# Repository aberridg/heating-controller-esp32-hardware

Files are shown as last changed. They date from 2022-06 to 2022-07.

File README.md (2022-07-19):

# heating-controller-esp32-hardware

This is a multi-zone heating controller, based on an ESP-32.

It uses Triacs for switching the boiler, pump and thermostats.

Right now, it is set up for 3 zones plus Domestic Hot Water.

It's designed to be used with this firmware:

https://github.com/aberridg/heating-controller-esp32-mqtt

The design can be used with physical thermostats or with triggering
via MQTT (for use with home automation systems such as Home Assistant).

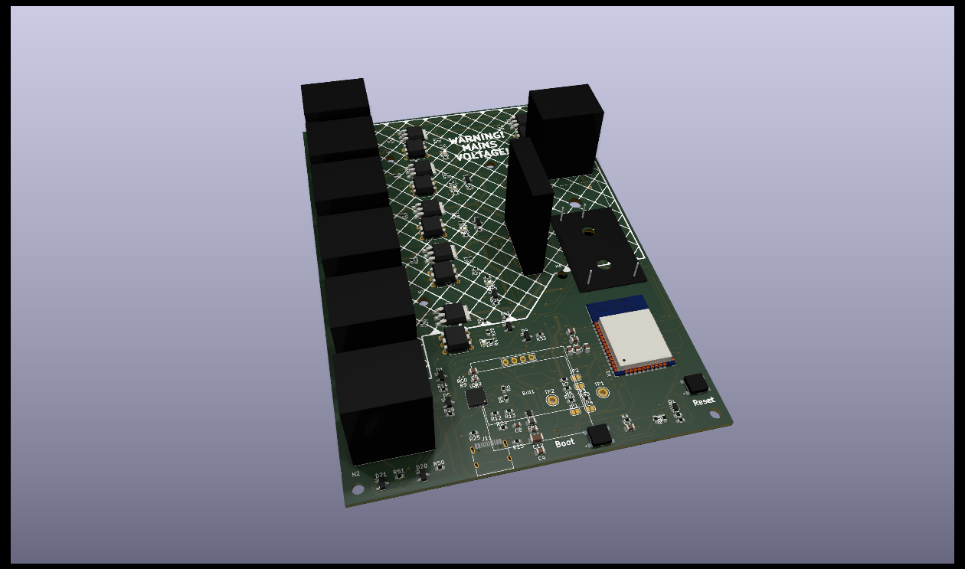
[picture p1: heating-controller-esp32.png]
3D Rendering of PCB


[Schematic](/heating-controller-esp32.pdf)

I'm having some PCBs made/assembled by JLCPCB, so if you want one, let me know (via LinkedIn - link in my bio)! Or if you can't do that, raise an issue.

IMPORTANT: v1.0 - the connector for the thermostats is the wrong way round on the PCB, so the pin numbers are not consistent with the others. No matter, just wire accordingly. For reference, GND is the upper pin, closest to the bottom edge of the board.

Also IMPORTANT: v1.0 - to flash the ESP32, hold down the Boot button and press reset.

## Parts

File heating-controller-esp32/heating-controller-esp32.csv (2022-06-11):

Comment | Designator | Footprint | LCSC
SSD1306 | Brd1 | Andrew_Custom:128x64OLED
1uF | C1,C6 | Capacitor_SMD:C_0805_2012Metric | C28323
4.7uF | C10 | Capacitor_SMD:C_0603_1608Metric | C19666
10uF | C12 | Capacitor_SMD:C_1206_3216Metric | C7171
100nF | C2,C3,C5,C7,C9 | Capacitor_SMD:C_0805_2012Metric | C49678
1.0uF | C4 | Capacitor_SMD:C_0805_2012Metric | C28323
10nF/100V | C8,C11 | Capacitor_SMD:C_0603_1608Metric | C84709
RED | D14,D15,D16,D17,D18,D19 | LED_SMD:LED_0603_1608Metric | C2286
ACS2 | D2,D3,D4,D6,D11,D12 | Package_TO_SOT_SMD:TO-252-3_TabPin4
~ | D1,D5,D7,D8,D9,D10,D13,D20,D21 | Package_TO_SOT_SMD:SOT-23 | C255581
LVR200S-240 | F1 | SamacSys_Parts:LVR200S240
MF-RM005_240-2 | F2 | SamacSys_Parts:MFRM0052402
Ferrite_Bead | FB1 | Inductor_SMD:L_0805_2012Metric | C1015
MountingHole | H1,H2,H3,H4,H5,H6,H7,H8 | MountingHole:MountingHole_3.2mm_M3_DIN965
431151015826 | J1,J2 | SamacSys_Parts:431151015826 | C318884
USB_C_Receptacle_USB2.0 | J11 | Connector_USB:USB_C_Receptacle_HRO_TYPE-C-31-M-12 | C165948
76829-0104 | J3,J4,J5,J6,J7,J8,J9 | SamacSys_Parts:736303
i2cPU | JP1,JP4 | Jumper:SolderJumper-2_P1.3mm_Bridged_RoundedPad1.0x1.5mm
SolderJumper_2_Bridged | JP2 | Jumper:SolderJumper-2_P1.3mm_Open_RoundedPad1.0x1.5mm
SolderJumper_2_Bridged | JP3 | Jumper:SolderJumper-2_P1.3mm_Bridged_RoundedPad1.0x1.5mm
IRM-01-3.3 | PS1 | SamacSys_Parts:IRM015
MBT3904DW1 | Q1 | Package_TO_SOT_SMD:SOT-363_SC-70-6 | C896759
12K | R1 | Resistor_SMD:R_0603_1608Metric | C22790
47K | R10 | Resistor_SMD:R_0402_1005Metric | C25792
470R | R12,R13 | Resistor_SMD:R_0603_1608Metric | C23179
270R | R15,R18,R21,R28,R35,R38 | Resistor_SMD:R_0603_1608Metric | C22966
360R | R16,R17,R19,R20,R22,R27,R29,R30,R36,R37,R39,R40 | Resistor_SMD:R_0603_1608Metric | C25194
1M | R23 | Resistor_SMD:R_0603_1608Metric | C22935
5.1K | R24 | Resistor_SMD:R_0603_1608Metric | C23186
~ | R14,R25,R26,R31,R32,R33,R34,R41,R50,R51 | Resistor_SMD:R_0603_1608Metric | C23162
22R | R4 | Resistor_SMD:R_0603_1608Metric | C23345
10K | R2,R3,R7,R8,R11,R42,R43 | Resistor_SMD:R_0603_1608Metric | C25804
1K | R44,R45,R46,R47,R48,R49 | Resistor_SMD:R_0603_1608Metric | C21190
27R | R5,R6 | Resistor_SMD:R_0603_1608Metric | C22966
24K | R9 | Resistor_SMD:R_0402_1005Metric | C25769
TestPoint | TP1,TP2 | TestPoint:TestPoint_Keystone_5005-5009_Compact
ESP32-WROOM-32U | U1 | RF_Module:ESP32-WROOM-32 | C82899
CP2102N-A01-GQFN28 | U2 | Package_DFN_QFN:QFN-28-1EP_5x5mm_P0.5mm_EP3.35x3.35mm | C6568
MOC3061M | U4,U6,U7,U8,U9,U10 | Package_DIP:DIP-6_W7.62mm | C8918
~ | U5 | Package_TO_SOT_SMD:SOT-666 | C15999

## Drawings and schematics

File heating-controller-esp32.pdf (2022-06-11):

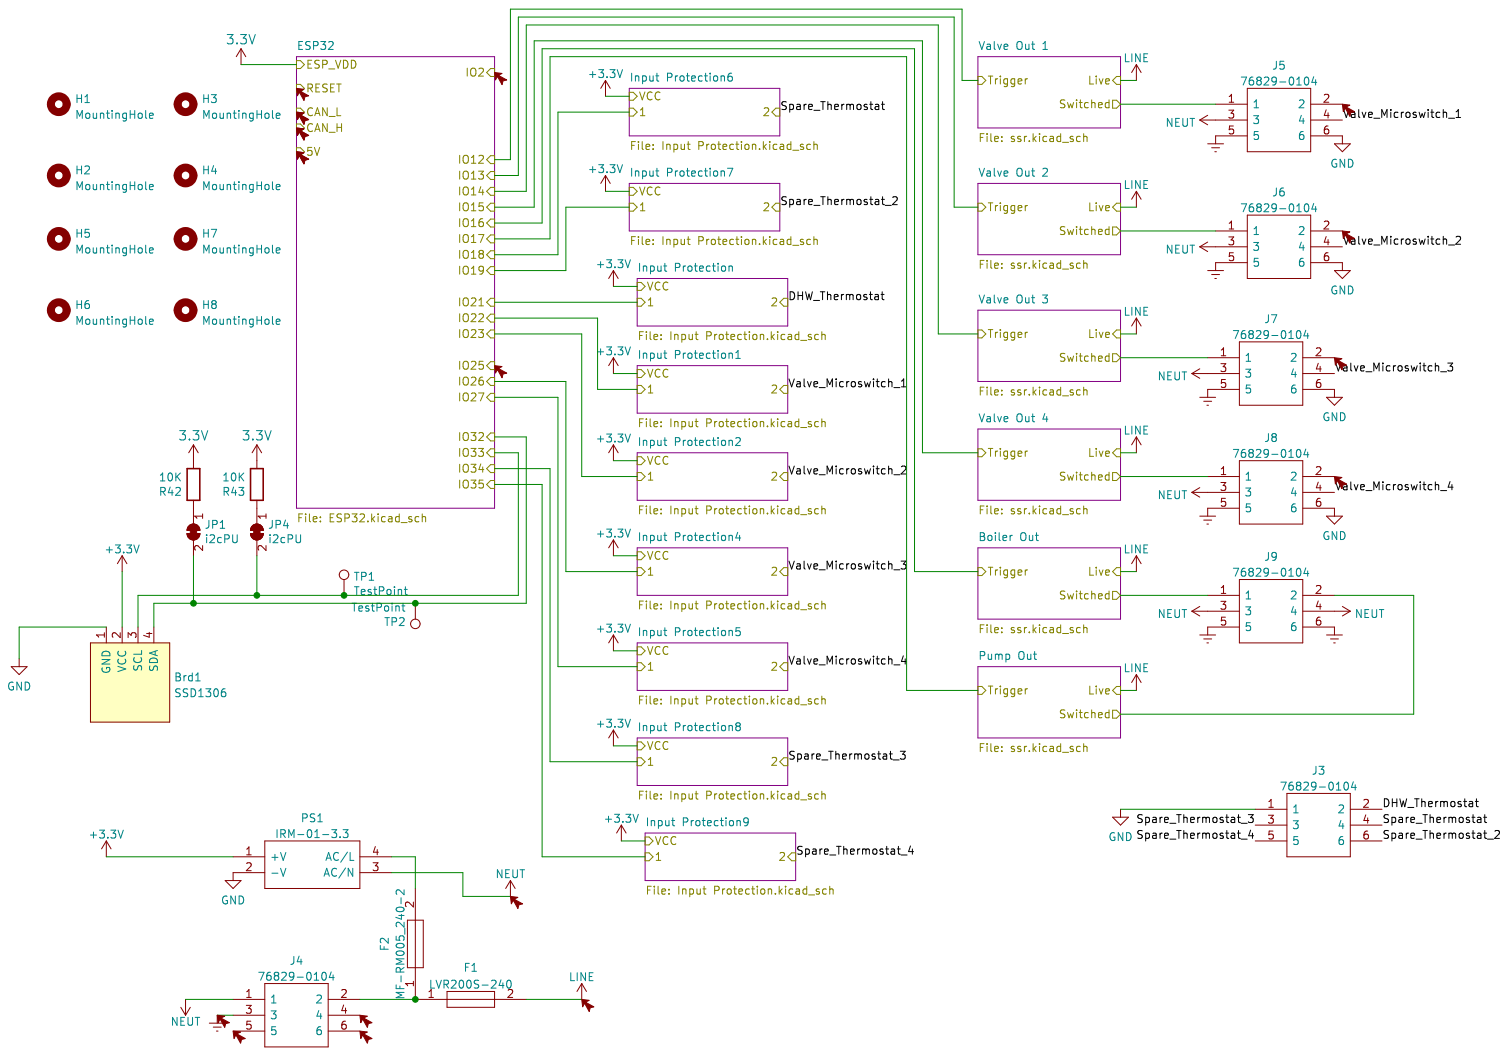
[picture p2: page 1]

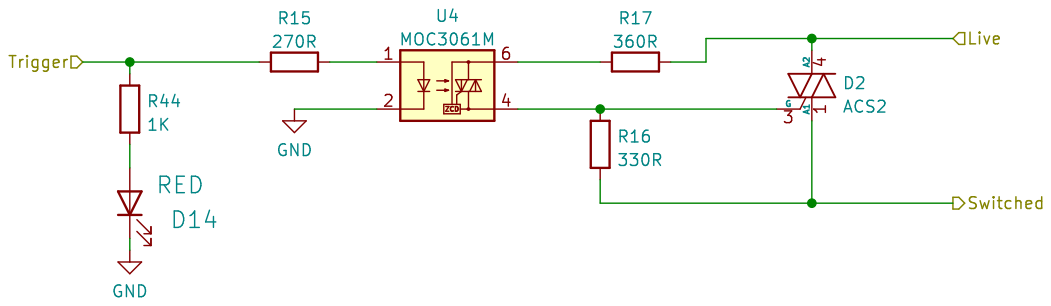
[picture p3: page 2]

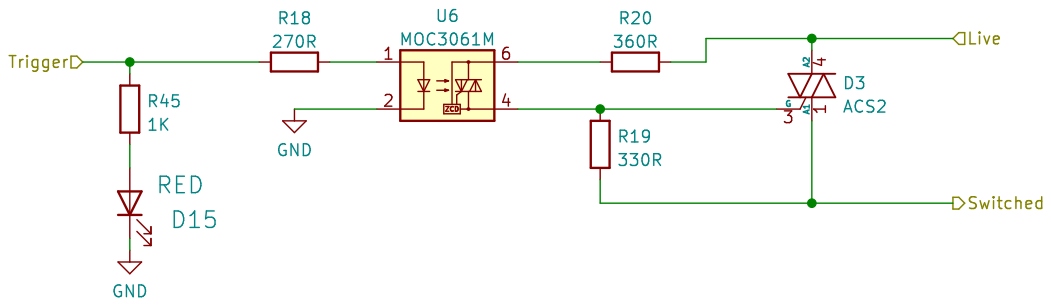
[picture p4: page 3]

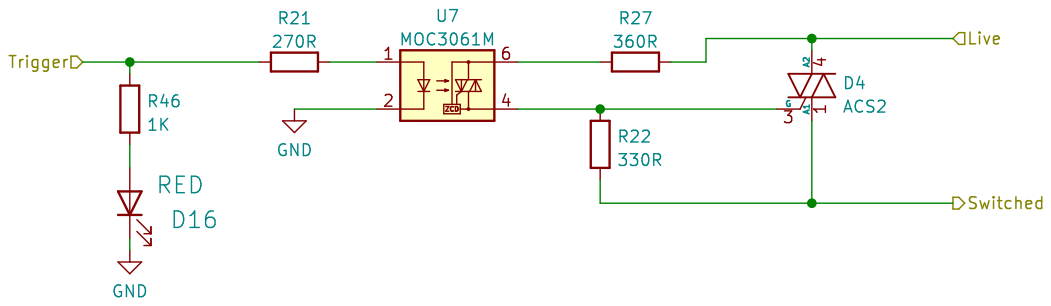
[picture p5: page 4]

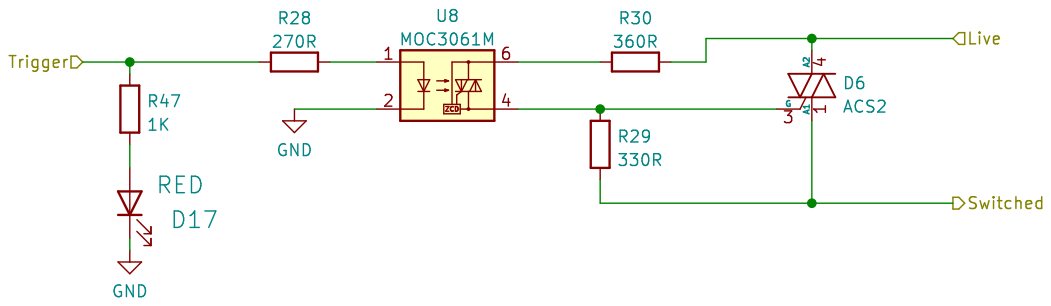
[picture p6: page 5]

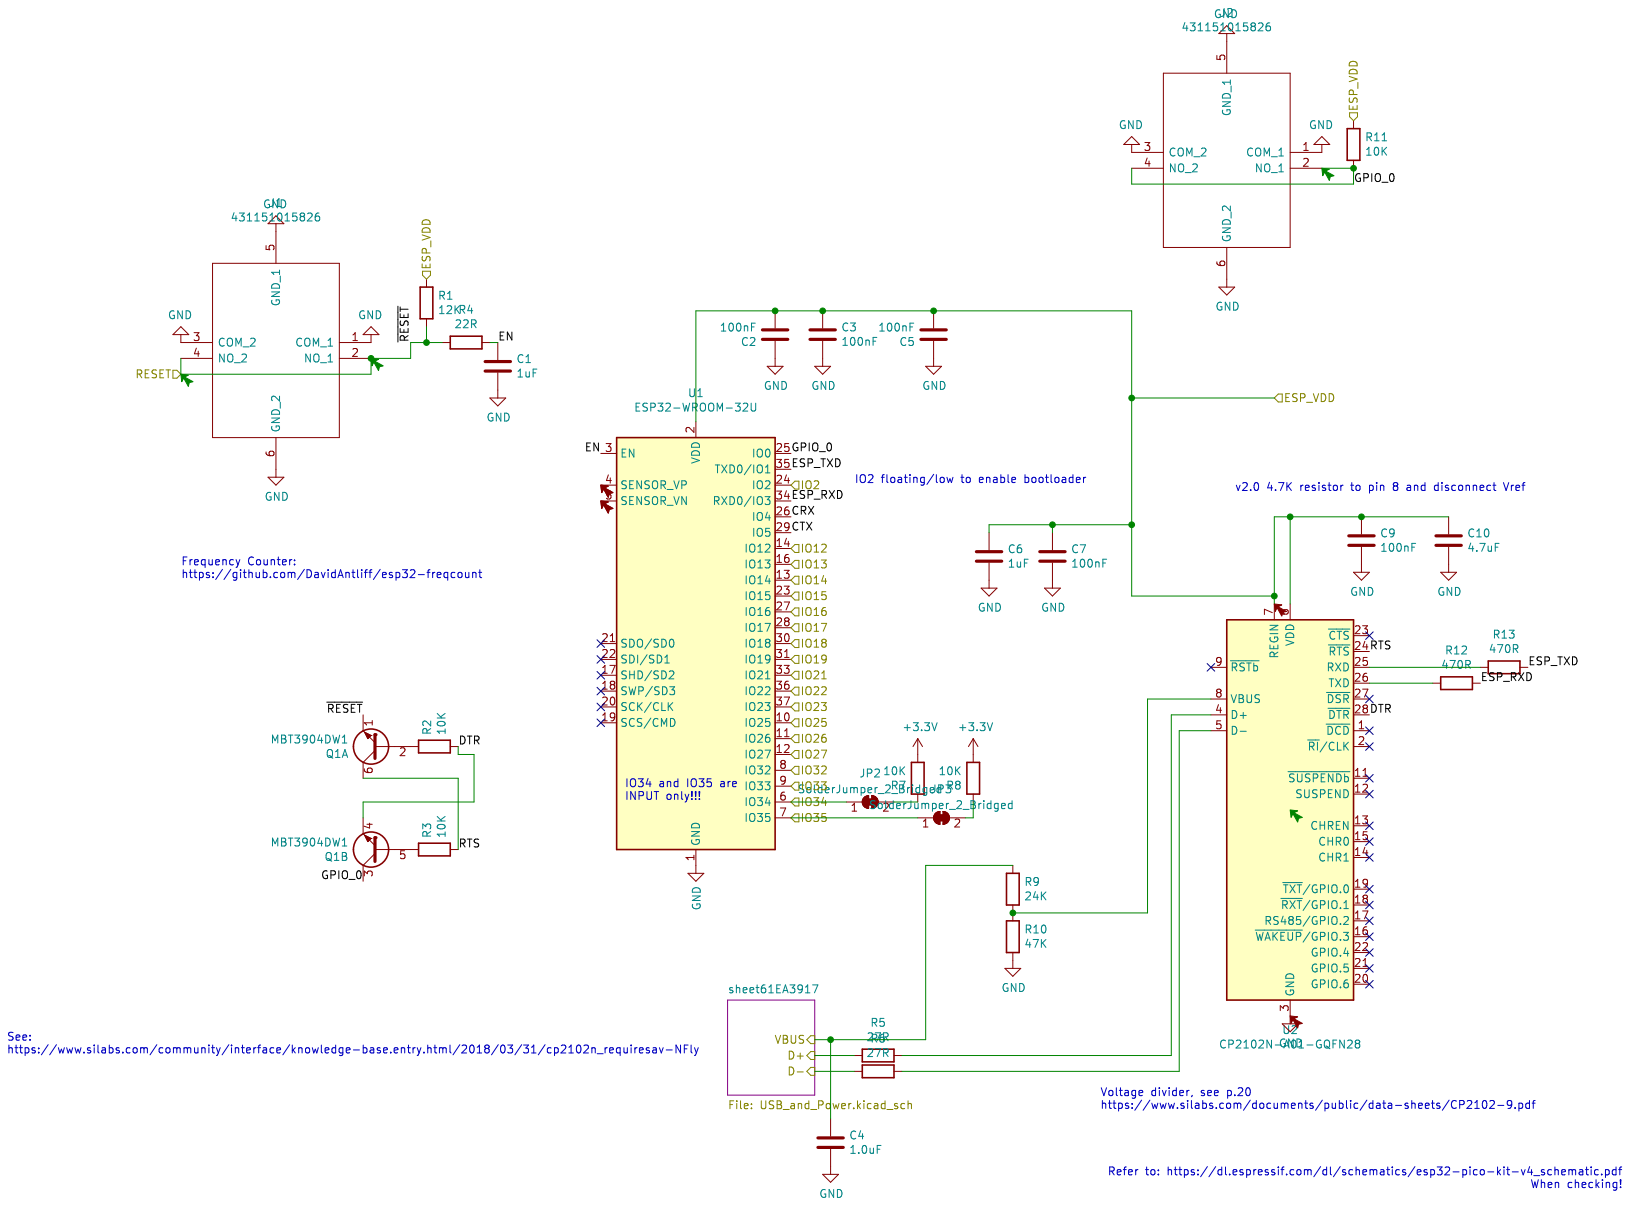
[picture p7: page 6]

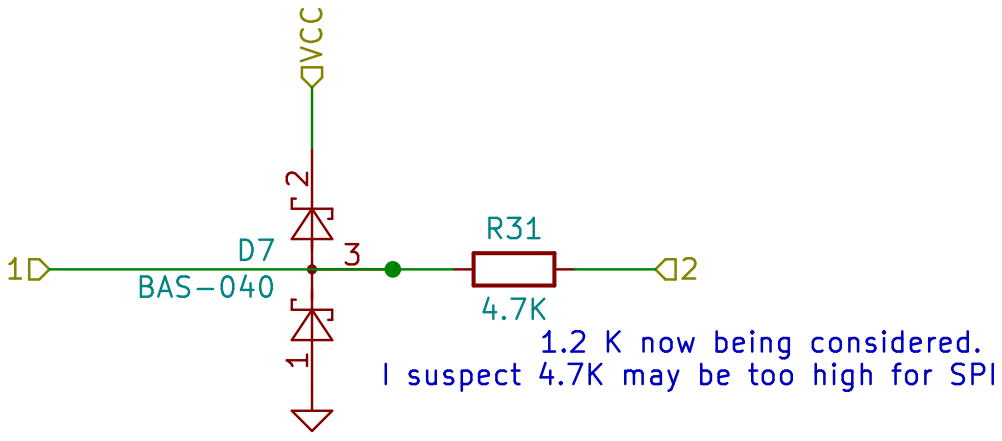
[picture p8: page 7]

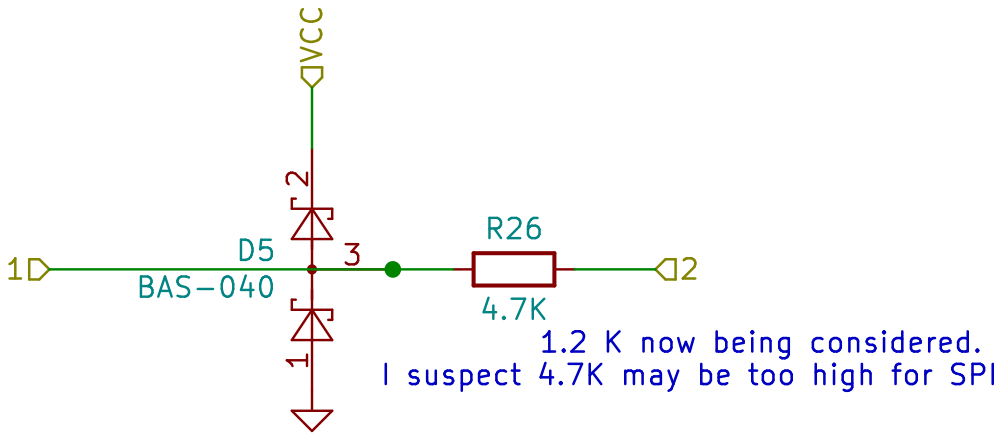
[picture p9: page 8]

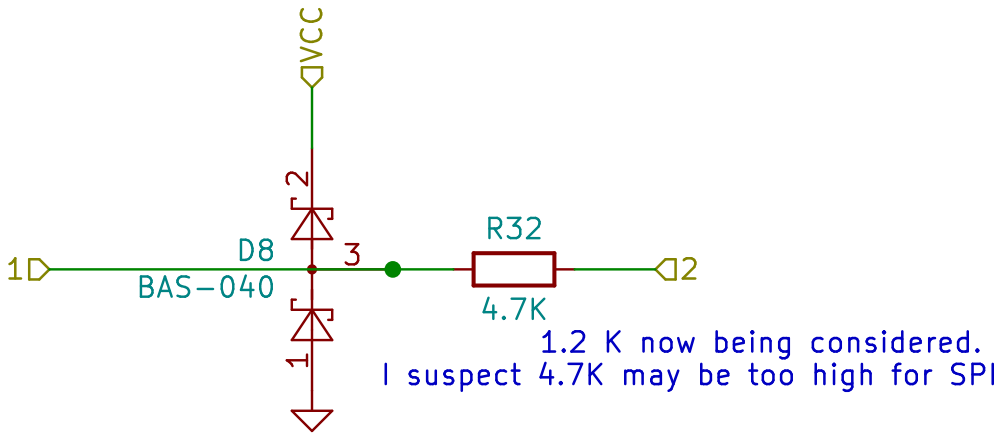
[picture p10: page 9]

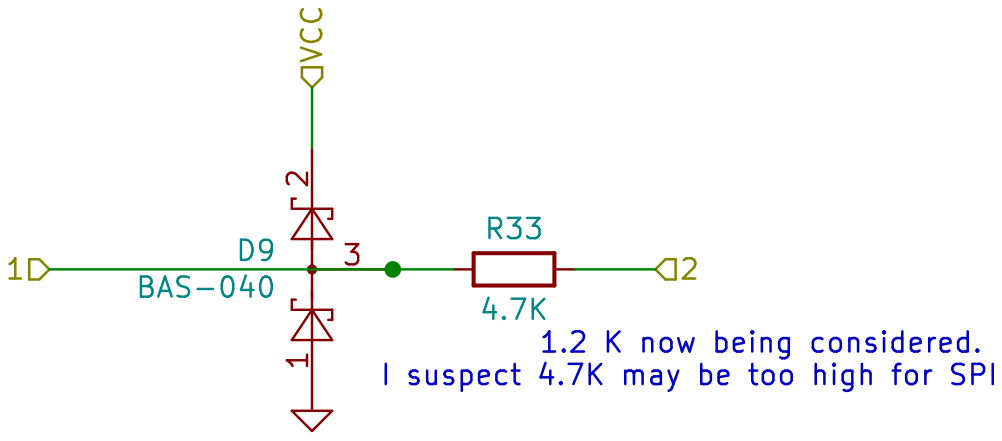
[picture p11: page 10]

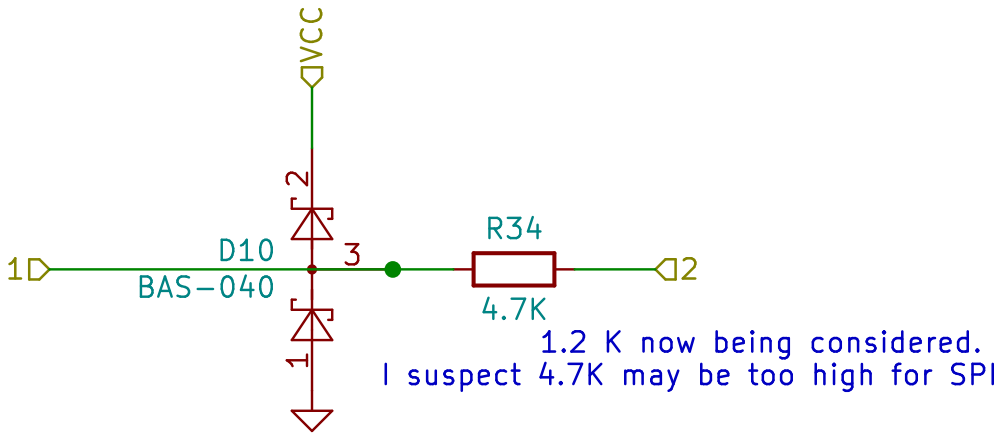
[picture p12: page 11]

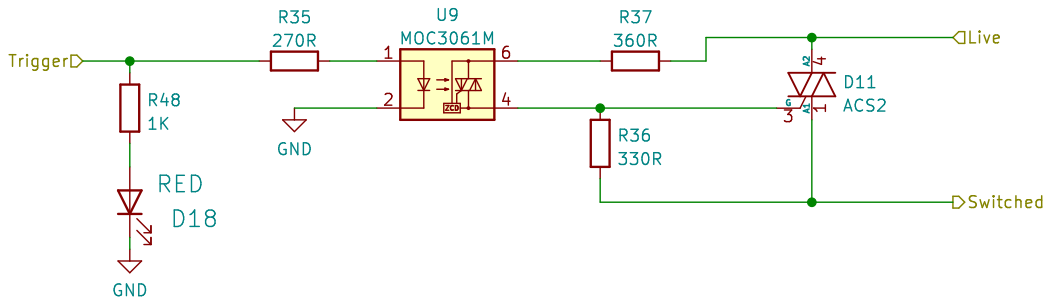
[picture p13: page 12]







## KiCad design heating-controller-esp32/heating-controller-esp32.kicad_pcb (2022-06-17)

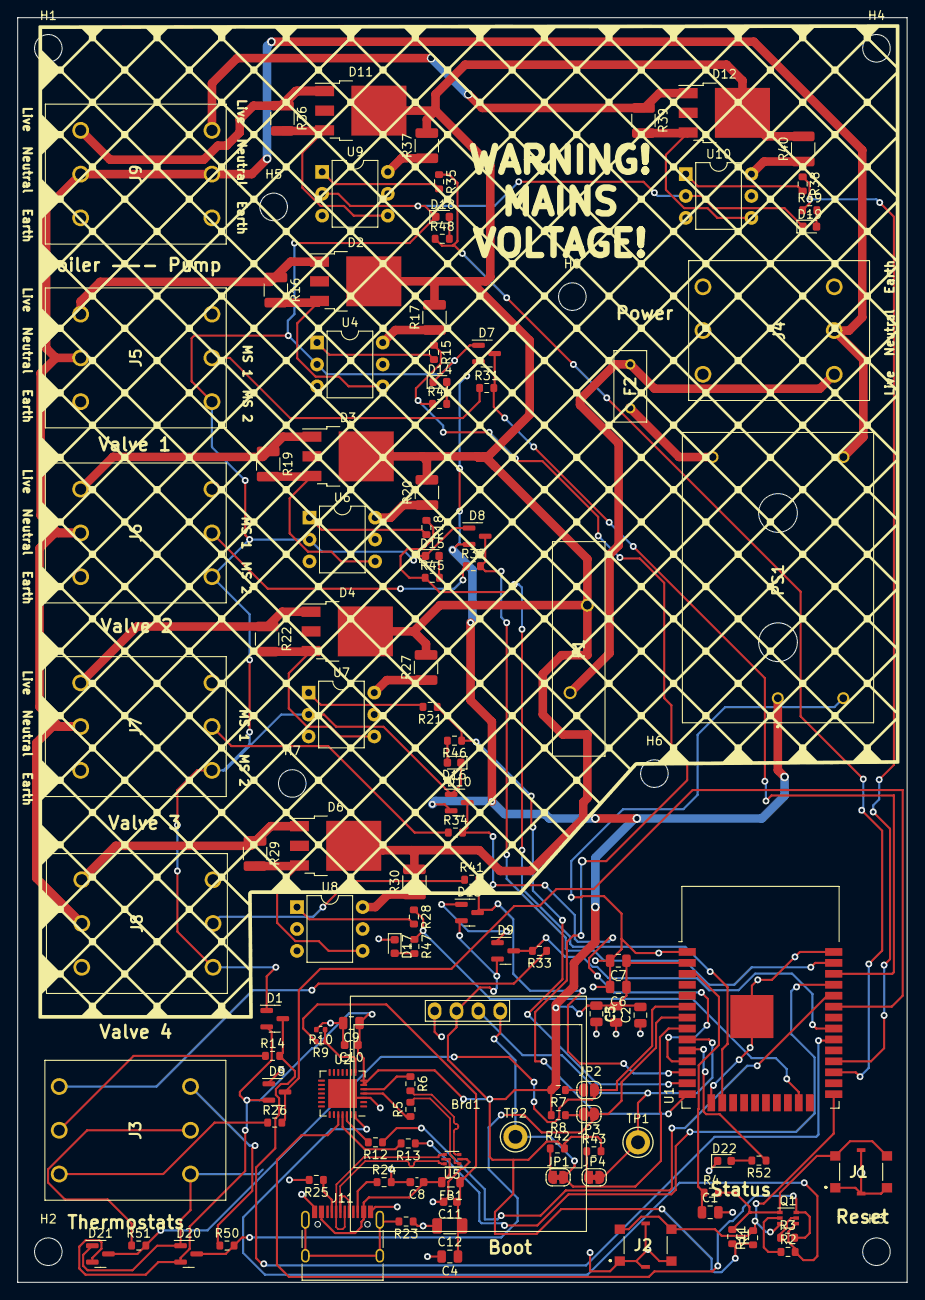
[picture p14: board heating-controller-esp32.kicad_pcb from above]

Board: 2 copper layers, 103.3 x 146.8 mm, 125 parts (0 on the bottom side), 92 nets.

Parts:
Brd1: SSD1306; 128x64OLED
C1, C6: 1uF; C_0805_2012Metric
C2, C3, C5, C7, C9: 100nF; C_0805_2012Metric
C4: 1.0uF; C_0805_2012Metric
C8, C11: 10nF/100V; C_0603_1608Metric
C10: 4.7uF; C_0603_1608Metric
C12: 10uF; C_1206_3216Metric
D1, D5, D7, D8, D9, D10, D13, D20, D21: BAS-040; SOT-23
D2, D3, D4, D6, D11, D12: ACS2; TO-252-3_TabPin4
D14, D15, D16, D17, D18, D19, D22: RED; LED_0603_1608Metric
F1: LVR200S-240; LVR200S240
F2: MF-RM005_240-2; MFRM0052402
FB1: Ferrite_Bead; L_0805_2012Metric
H1, H2, H3, H4, H5, H6, H7, H8: MountingHole; MountingHole_3.2mm_M3_DIN965
J1, J2: 431151015826
J3, J4, J5, J6, J7, J8, J9: 76829-0104; 736303
J11: USB_C_Receptacle_USB2.0; USB_C_Receptacle_HRO_TYPE-C-31-M-12
JP1, JP4: i2cPU; SolderJumper-2_P1.3mm_Bridged_RoundedPad1.0x1.5mm
JP2: SolderJumper_2_Bridged; SolderJumper-2_P1.3mm_Open_RoundedPad1.0x1.5mm
JP3: SolderJumper_2_Bridged; SolderJumper-2_P1.3mm_Bridged_RoundedPad1.0x1.5mm
PS1: IRM-01-3.3; IRM015
Q1: MBT3904DW1; SOT-363_SC-70-6
R1: 12K; R_0603_1608Metric
R2, R3, R7, R8, R11, R42, R43: 10K; R_0603_1608Metric
R4: 22R; R_0603_1608Metric
R5, R6: 27R; R_0603_1608Metric
R9: 24K; R_0402_1005Metric
R10: 47K; R_0402_1005Metric
R12, R13: 470R; R_0603_1608Metric
R14, R26, R31, R32, R33, R34, R41, R50, R51: 4.7K; R_0603_1608Metric
R15, R18, R21, R28, R35, R38: 270R; R_0603_1608Metric
R16, R17, R19, R20, R22, R27, R29, R30, R36, R37, R39, R40: 360R; R_1210_3225Metric
R23: 1M; R_0603_1608Metric
R24, R25: 5.1K; R_0603_1608Metric
R44, R45, R46, R47, R48, R49, R52: 1K; R_0603_1608Metric
TP1, TP2: TestPoint; TestPoint_Keystone_5005-5009_Compact
U1: ESP32-WROOM-32U; ESP32-WROOM-32
U2: CP2102N-A01-GQFN28; QFN-28-1EP_5x5mm_P0.5mm_EP3.35x3.35mm
U4, U6, U7, U8, U9, U10: MOC3061M; DIP-6_W7.62mm
U5: USB ESD; SOT-666

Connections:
+3V3: Brd1.2 (VCC), C2.2, C3.1, C5.2, C6.1, C7.1, C9.1, C10.1, D1.2, D5.2, D7.2, D8.2, D9.2, D10.2, D13.2, D20.2, D21.2, PS1.1 (+V), R1.1, R7.2, R8.2, R11.1, R42.2, R43.2, U1.2 (VDD), U2.6 (VDD), U2.7 (REGIN)
/Boiler Out/Switched: D11.1 (A1), J9.1, R36.1
/Boiler Out/Trigger: R35.1, R48.1, U1.27 (IO16)
/DHW_Thermostat: J3.2, R26.1
/ESP32/DTR: Q1.4 (E2), R2.2, U2.28 (~DTR)
/ESP32/EN: C1.1, R4.1, U1.3 (EN)
/ESP32/ESP_RXD: R12.1, U1.34 (RXD0/IO3)
/ESP32/ESP_TXD: R13.1, U1.35 (TXD0/IO1)
/ESP32/GPIO_0: J2.2 (NO_1), J2.4 (NO_2), Q1.3 (C2), R11.2, U1.25 (IO0)
/ESP32/IO12: R15.1, R44.1, U1.14 (IO12)
/ESP32/IO13: R18.1, R45.1, U1.16 (IO13)
/ESP32/IO14: R21.1, R46.1, U1.13 (IO14)
/ESP32/IO15: R28.1, R47.1, U1.23 (IO15)
/ESP32/IO17: R38.1, R49.1, U1.28 (IO17)
/ESP32/IO18: D1.3, R14.2, U1.30 (IO18)
/ESP32/IO19: D9.3, R33.2, U1.31 (IO19)
/ESP32/IO21: D5.3, R26.2, U1.33 (IO21)
/ESP32/IO22: D7.3, R31.2, U1.36 (IO22)
/ESP32/IO23: D8.3, R32.2, U1.37 (IO23)
/ESP32/IO26: D10.3, R34.2, U1.11 (IO26)
/ESP32/IO27: D13.3, R41.2, U1.12 (IO27)
/ESP32/IO32: Brd1.4 (SDA), JP1.2 (B), TP2.1, U1.8 (IO32)
/ESP32/IO33: Brd1.3 (SCL), JP4.2 (B), TP1.1, U1.9 (IO33)
/ESP32/IO34: D21.3, JP2.1 (A), R51.2, U1.6 (IO34)
/ESP32/IO35: D20.3, JP3.1 (A), R50.2, U1.7 (IO35)
/ESP32/RTS: Q1.6 (C1), R3.2, U2.24 (~RTS)
/ESP32/sheet61EA3917/D+: R5.2, U5.1 (I/O1)
/ESP32/sheet61EA3917/D-: R6.2, U5.3 (I/O2)
/ESP32/sheet61EA3917/USB_D+: J11.A6 (D+), J11.B6 (D+), U5.6 (I/O1)
/ESP32/sheet61EA3917/USB_D-: J11.A7 (D-), J11.B7 (D-), U5.4 (I/O2)
/ESP32/sheet61EA3917/VBUS: C4.1, C11.1, C12.1, FB1.1, R9.1
/ESP32/~RESET: J1.2 (NO_1), J1.4 (NO_2), Q1.1 (E1), R1.2, R4.2
/Pump Out/Switched: D12.1 (A1), J9.2, R39.1
/STATUS_LED: R52.1, U1.10 (IO25)
/Spare_Thermostat: J3.4, R14.1
/Spare_Thermostat_2: J3.6, R33.1
/Spare_Thermostat_3: J3.3, R51.1
/Spare_Thermostat_4: J3.5, R50.1
/Valve Out 1/Switched: D2.1 (A1), J5.1, R16.1
/Valve Out 2/Switched: D3.1 (A1), J6.1, R19.1
/Valve Out 3/Switched: D4.1 (A1), J7.1, R22.1
/Valve Out 4/Switched: D6.1 (A1), J8.1, R29.1
/Valve_Microswitch_1: J5.4, R31.1
/Valve_Microswitch_2: J6.4, R32.1
/Valve_Microswitch_3: J7.4, R34.1
/Valve_Microswitch_4: J8.4, R41.1
Earth: J4.5, J5.5, J6.5, J7.5, J8.5, J9.5, J9.6
GND: Brd1.1 (GND), C1.2, C2.1, C3.2, C4.2, C5.1, C6.2, C7.2, C8.2, C9.2, C10.2, C11.2, C12.2, D1.1, D5.1, D7.1, D8.1, D9.1, D10.1, D13.1, D14.1 (K), D15.1 (K), D16.1 (K), D17.1 (K), D18.1 (K), D19.1 (K), D20.1, D21.1, D22.1 (K), J1.1 (COM_1), J1.3 (COM_2), J1.5 (GND_1), J1.6 (GND_2), J2.1 (COM_1), J2.3 (COM_2), J2.5 (GND_1), J2.6 (GND_2), J3.1, J5.6, J6.6, J7.6, J8.6, J11.A1 (GND), J11.A12 (GND), J11.B1 (GND), J11.B12 (GND), PS1.2 (-V), R10.2, R23.1, R24.2, R25.2, U1.1 (GND), U1.15 (GND), U1.38 (GND), U1.39 (GND), U2.3 (GND), U2.29 (GND), U4.2, U5.2 (GND), U6.2, U7.2, U8.2, U9.2, U10.2
LINE: D2.4 (A2), D3.4 (A2), D4.4 (A2), D6.4 (A2), D11.4 (A2), D12.4 (A2), F1.2, R17.2, R20.2, R27.2, R30.2, R37.2, R40.2
NEUT: J4.3, J5.3, J6.3, J7.3, J8.3, J9.3, J9.4, PS1.3 (AC/N)
unnamed: C8.1, FB1.2, J11.A4 (VBUS), J11.A9 (VBUS), J11.B4 (VBUS), J11.B9 (VBUS), U5.5 (VBUS)
unnamed: D2.3 (G), R16.2, U4.4
unnamed: D3.3 (G), R19.2, U6.4
unnamed: D4.3 (G), R22.2, U7.4
unnamed: D6.3 (G), R29.2, U8.4
unnamed: D11.3 (G), R36.2, U9.4
unnamed: D12.3 (G), R39.2, U10.4
unnamed: D14.2 (A), R44.2
unnamed: D15.2 (A), R45.2
unnamed: D16.2 (A), R46.2
unnamed: D17.2 (A), R47.2
unnamed: D18.2 (A), R48.2
unnamed: D19.2 (A), R49.2
unnamed: D22.2 (A), R52.2
unnamed: F1.1, F2.1, J4.1
unnamed: F2.2, PS1.4 (AC/L)
unnamed: J11.A5 (CC1), R25.1
unnamed: J11.B5 (CC2), R24.1
unnamed: J11.S1 (SHIELD), R23.2
unnamed: JP1.1 (A), R42.1
unnamed: JP2.2 (B), R7.1
unnamed: JP3.2 (B), R8.1
unnamed: JP4.1 (A), R43.1
unnamed: Q1.2 (B1), R2.1
unnamed: Q1.5 (B2), R3.1
unnamed: R5.1, U2.4 (D+)
unnamed: R6.1, U2.5 (D-)
unnamed: R9.2, R10.1, U2.8 (VBUS)
unnamed: R12.2, U2.26 (TXD)
unnamed: R13.2, U2.25 (RXD)
unnamed: R15.2, U4.1
unnamed: R17.1, U4.6
unnamed: R18.2, U6.1
unnamed: R20.1, U6.6
unnamed: R21.2, U7.1
unnamed: R27.1, U7.6
unnamed: R28.2, U8.1
unnamed: R30.1, U8.6
unnamed: R35.2, U9.1
unnamed: R37.1, U9.6
unnamed: R38.2, U10.1
unnamed: R40.1, U10.6

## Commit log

2022-06-09 First commit of initial schematic design
    [ESP32.kicad_sch, Input protection.kicad_sch, USB_and_Power.kicad_sch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]
2022-06-10 Initial design of schematic complete. Started laying out PCB
    [ESP32.kicad_sch, Input protection.kicad_sch, USB_and_Power.kicad_sch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]
2022-06-11 Changed to Wago connectors; initial routing completed
    [ESP32.kicad_sch, heating-controller-esp32.kicad_pcb, heating-controller-esp32.kicad_sch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]
2022-06-11 Minor tweaks
    [heating-controller-esp32.kicad_pcb]
2022-06-11 Added additional spare thermostat inputs
    [ESP32.kicad_sch, heating-controller-esp32.kicad_pcb, heating-controller-esp32.kicad_sch]
2022-06-11 Mounting holes, a few more tweaks
    [ESP32.kicad_sch, Input protection.kicad_sch, USB_and_Power.kicad_sch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]
2022-06-11 Fabrication outputs
    [heating-controller-esp32-B_Cu.gbr, heating-controller-esp32-B_Mask.gbr, heating-controller-esp32-B_Paste.gbr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]
2022-06-11 Oops. Missing certain files for commit.
    [Input protection.kicad_sch, USB_and_Power.kicad_sch, heating-controller-esp32.csv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]
2022-06-11 Bringing in step with the other files
    [heating-controller-esp32.kicad_pcb]
2022-06-11 Changes for JLCB fabrication using https://github.com/Bouni/kicad-jlcpcb-tools
    [Input protection.kicad_sch, USB_and_Power.kicad_sch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]
2022-06-11 Minor updates and update of README.md
    [heating-controller-esp32.kicad_pcb, heating-controller-esp32.kicad_sch, ssr.kicad_sch]
2022-06-11 Added schematic pdf
2022-06-12 Current limiting resistors for MOC devices changed to 0.5W
    [ESP32.kicad_sch, USB_and_Power.kicad_sch, heating-controller-esp32.kicad_pcb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]
2022-06-13 Assign netclasses (should have done this earlier)! Small tweaks; status LED added.
    [heating-controller-esp32.kicad_pcb, heating-controller-esp32.kicad_sch]
2022-06-13 Ordered from JLCPCB.com as version 1.0
    [heating-controller-esp32-CuBottom.gbr, heating-controller-esp32-CuTop.gbr, heating-controller-esp32-EdgeCuts.gbr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]
2022-06-17 Not 100% sure what I did, but committing to keep in step with what's on my computer. Probably still v1.0
    [heating-controller-esp32.kicad_pcb]
2022-06-26 Added note about the connector for thermostats being the wrong way round on the PCB
